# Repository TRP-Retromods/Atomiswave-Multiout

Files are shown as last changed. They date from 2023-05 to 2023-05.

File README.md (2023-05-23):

# Atomiswave Multiout
---
Get Composite, RGB or S-Video output from your Atomiswave, using the VGA output

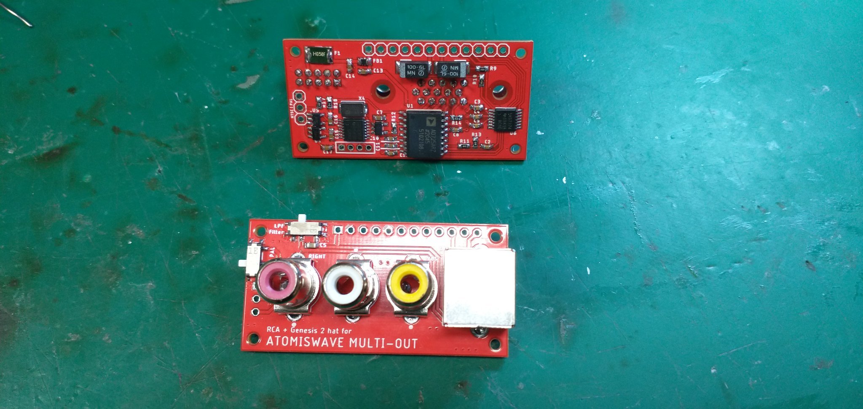
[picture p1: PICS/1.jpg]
PCB xemple

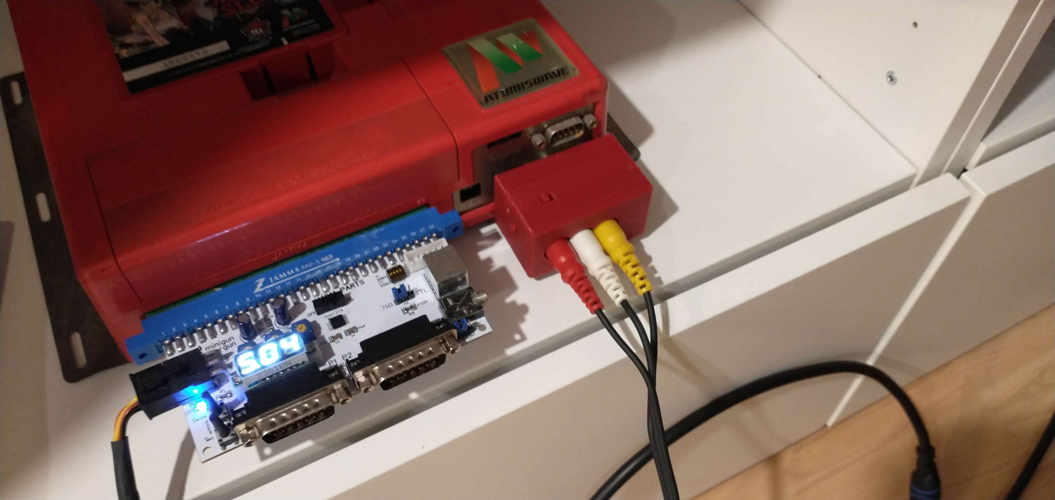
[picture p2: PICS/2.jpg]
workinunit exemple


(c) 2023 by The Real Phoenix
Design from Mike Chi's VGA2SCART

---

## Features:
- The motherboard is doing all the job, the "hat" or daughterboard is the one with the output connectors, so you can make one for your needs
- PAL/NTSC selection
- LP Filter
- Audio Line-in level is driven from the daughterboard, leaving the ability to keep pass-trought audio for amp already present inside a cabinet

## Notes:
- You'll need to program the CDCE either with using a DFO programmer or ask your ICs provider to do it for you.
- The connector to audio/power is tricky to find, I found some on eBay: https://www.ebay.ca/itm/184681041924

---
### Links for the Programmer and classic DFO:
https://nfggames.com/forum2/index.php?topic=5744.0
https://oshpark.com/profiles/micro

https://circuit-board.de/forum/index.php/Thread/7810-Sega-32X-Switchless-Mod-f%C3%BCr-Mega-Drive-1-und-auch-2/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

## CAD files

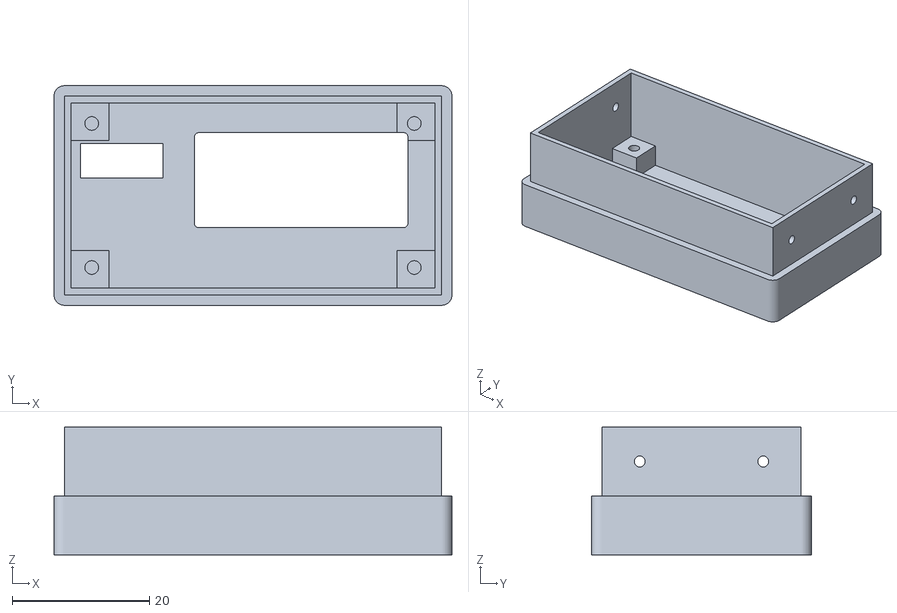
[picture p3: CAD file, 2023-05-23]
STL/Atomiswave_BOT.stl
58.0 x 32.0 x 18.6

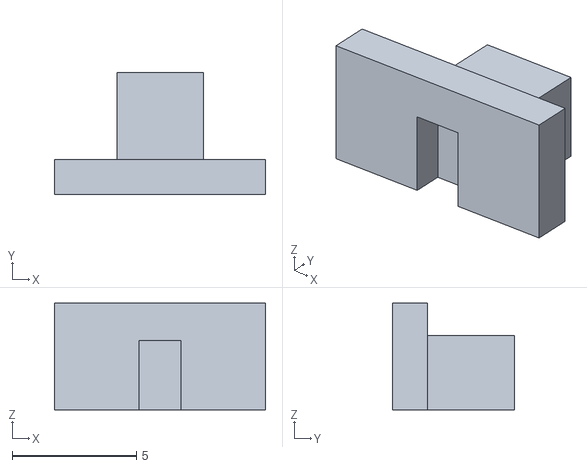
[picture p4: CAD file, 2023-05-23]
STL/Atomiswave_Buttn.stl
8.50 x 4.90 x 4.30

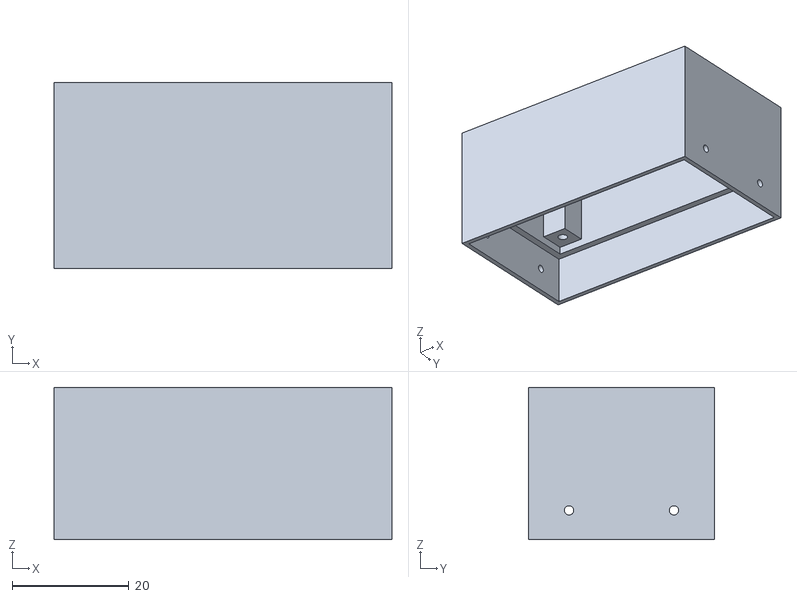
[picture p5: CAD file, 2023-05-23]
STL/Atomiswave_TOP_Empty.stl
58.0 x 32.0 x 26.1

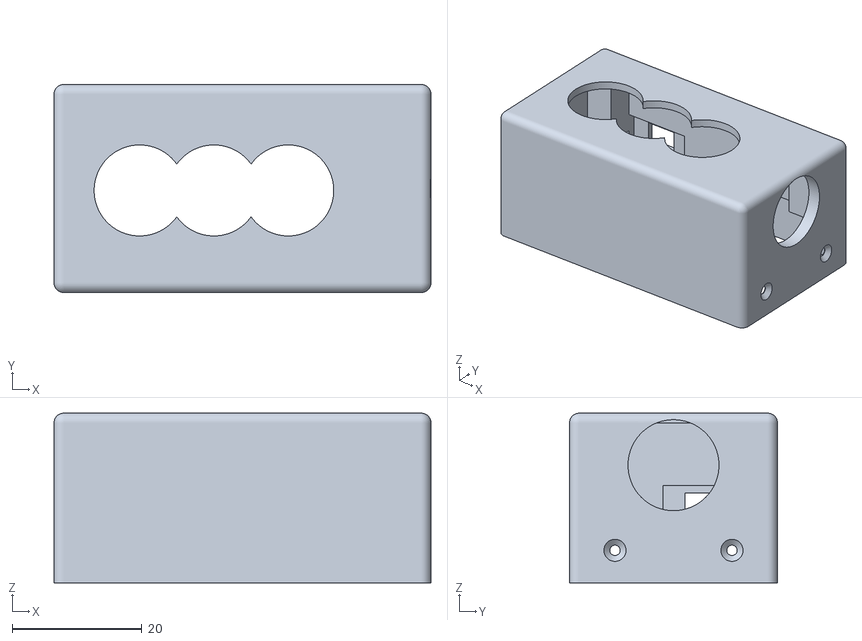
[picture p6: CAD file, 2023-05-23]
STL/Atomiswave_TOP.stl
58.0 x 32.0 x 26.1

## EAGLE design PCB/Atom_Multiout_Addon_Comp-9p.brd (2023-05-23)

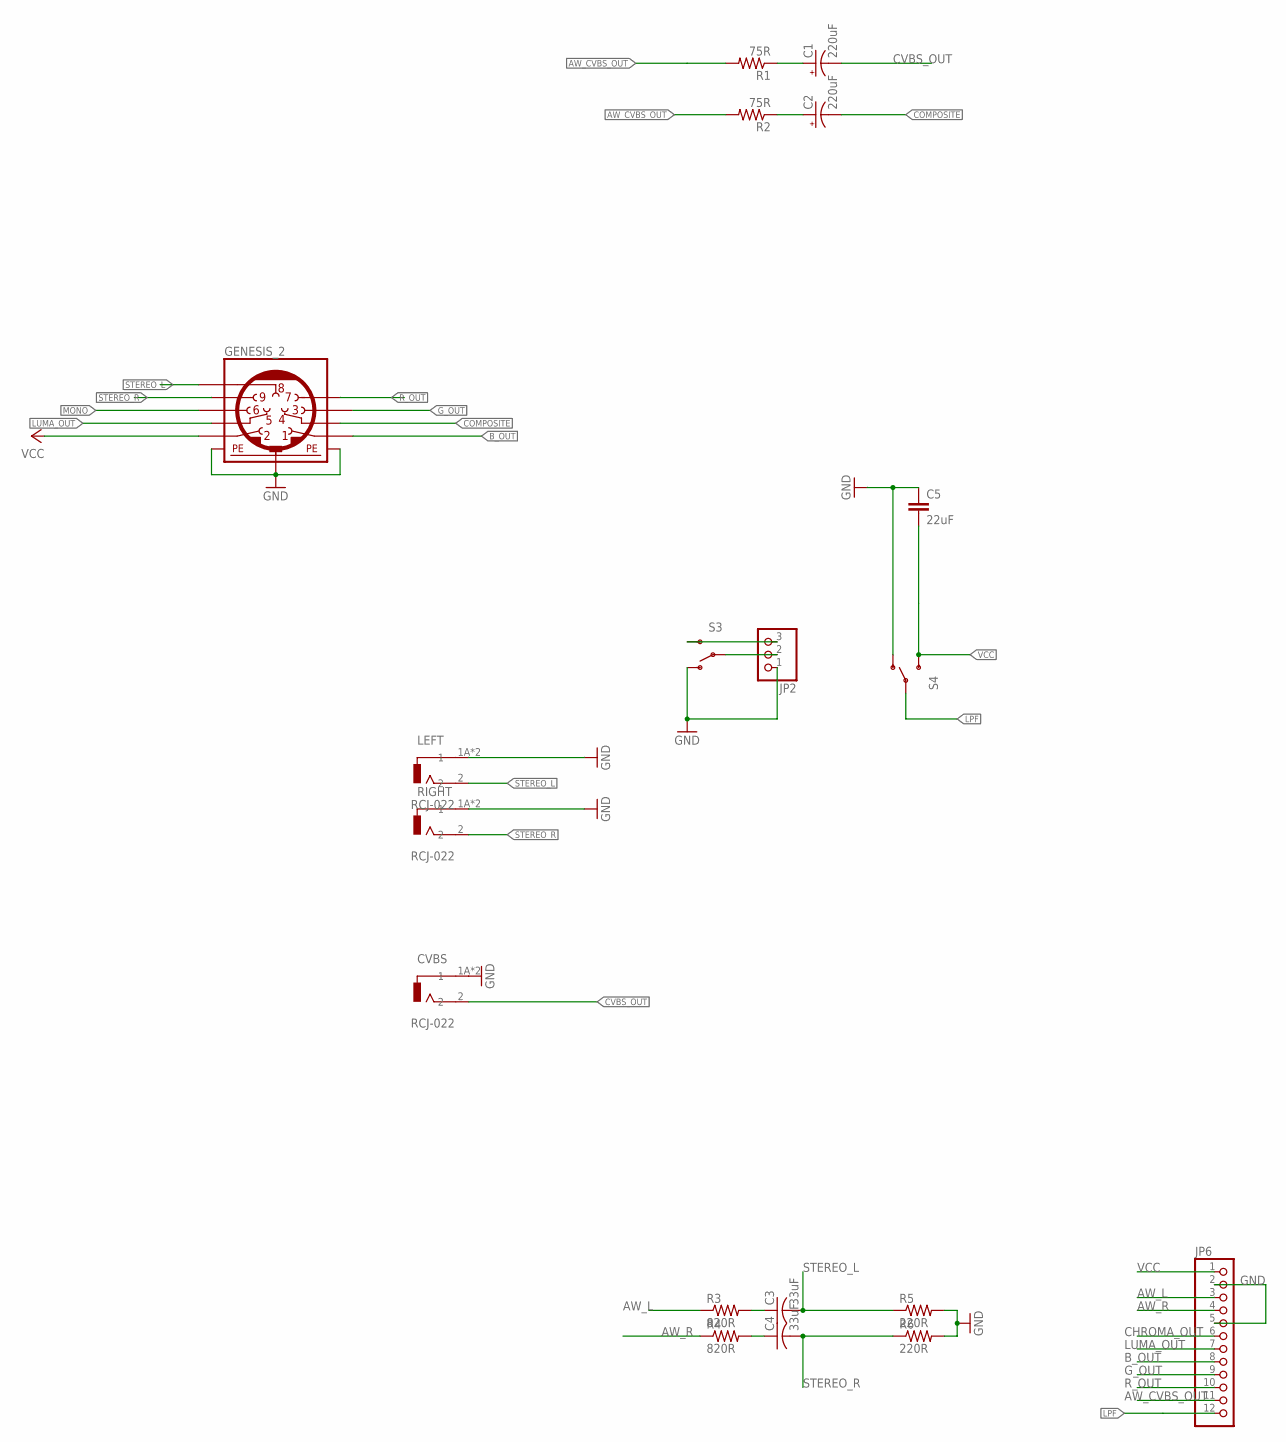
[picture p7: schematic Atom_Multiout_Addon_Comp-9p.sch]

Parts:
C1, C2: 220uF; D/7343-31W
C3, C4: 33uF; C1206K
C5: 22uF; C0603
CVBS: RCJ-022; CUI_RCJ-022
GENESIS_2: MINI_DIN_9; M_DIN9
JP2: PINHD-1X03_2.54-S; 1X03-S
JP6: PINHD-1X12_2.54-S; 1X12-S
LEFT: RCJ-022; CUI_RCJ-022
R1, R2: 75R; R1206
R3, R4: 820R; R1206
R5, R6: 220R; R1206
RIGHT: RCJ-022; CUI_RCJ-022
S3, S4: SWITCH-SPDT-SMD-A; SWITCH-SPST-SMD-A

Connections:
AW_CVBS_OUT: JP6.11, R1.2, R2.2
AW_L: JP6.3, R3.1
AW_R: JP6.4, R4.1
B_OUT: GENESIS_2.1, JP6.8
CHROMA_OUT: JP6.6
COMPOSITE: C2.-, GENESIS_2.4
CVBS_OUT: C1.-, CVBS.2
GND: C5.1, CVBS.1A (1), CVBS.1B (1), GENESIS_2.SH1 (PE1), GENESIS_2.SH2 (PE2), GENESIS_2.SH3 (PE3), JP2.1, JP6.2, JP6.5, LEFT.1A (1), LEFT.1B (1), R5.2, R6.2, RIGHT.1A (1), RIGHT.1B (1), S3.1 (O), S4.1 (O)
G_OUT: GENESIS_2.3, JP6.9
LPF: JP6.12, S4.2
LUMA_OUT: GENESIS_2.5, JP6.7
MONO: GENESIS_2.6
unnamed: C2.+, R2.1
unnamed: JP2.3, S3.3 (S)
unnamed: C1.+, R1.1
unnamed: C4.1, R4.2
unnamed: C3.1, R3.2
unnamed: JP2.2, S3.2
R_OUT: GENESIS_2.7, JP6.10
STEREO_L: C3.2, GENESIS_2.8, LEFT.2, R5.1
STEREO_R: C4.2, GENESIS_2.9, R6.1, RIGHT.2
VCC: C5.2, GENESIS_2.2, JP6.1, S4.3 (S)

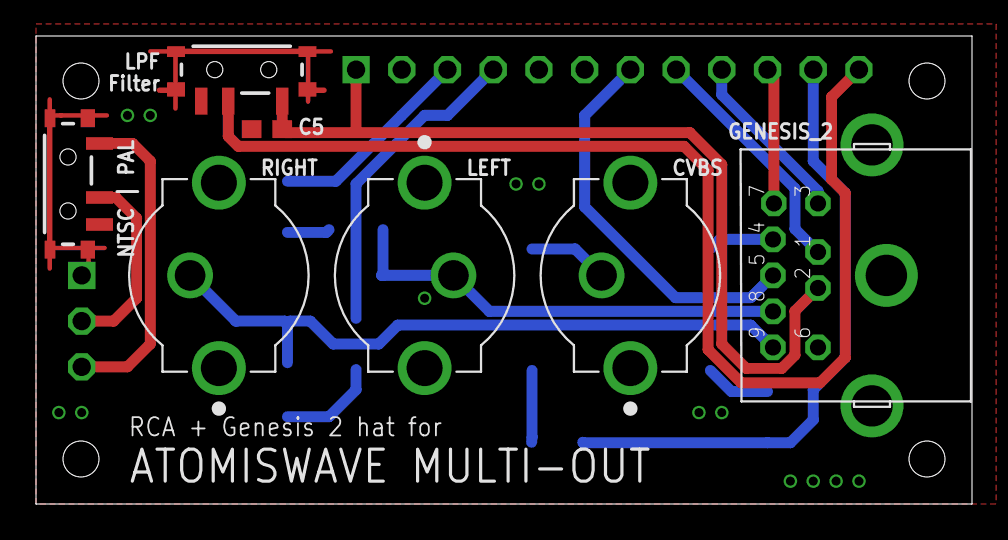
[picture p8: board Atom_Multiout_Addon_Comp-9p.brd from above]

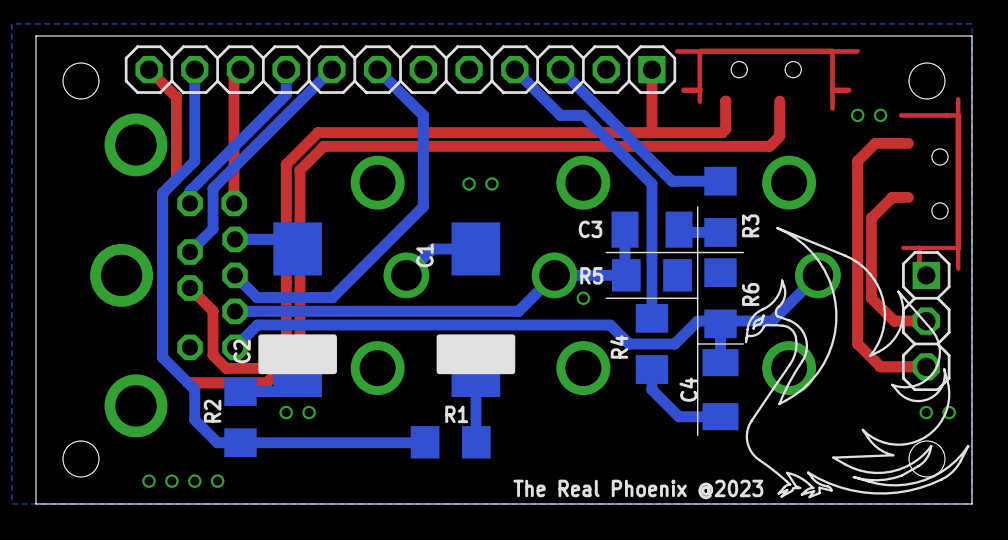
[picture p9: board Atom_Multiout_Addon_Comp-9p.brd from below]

Board: 2 copper layers, 52.0 x 26.0 mm, 20 parts (13 on the bottom side), 20 nets.

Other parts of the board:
U$1: LOGO

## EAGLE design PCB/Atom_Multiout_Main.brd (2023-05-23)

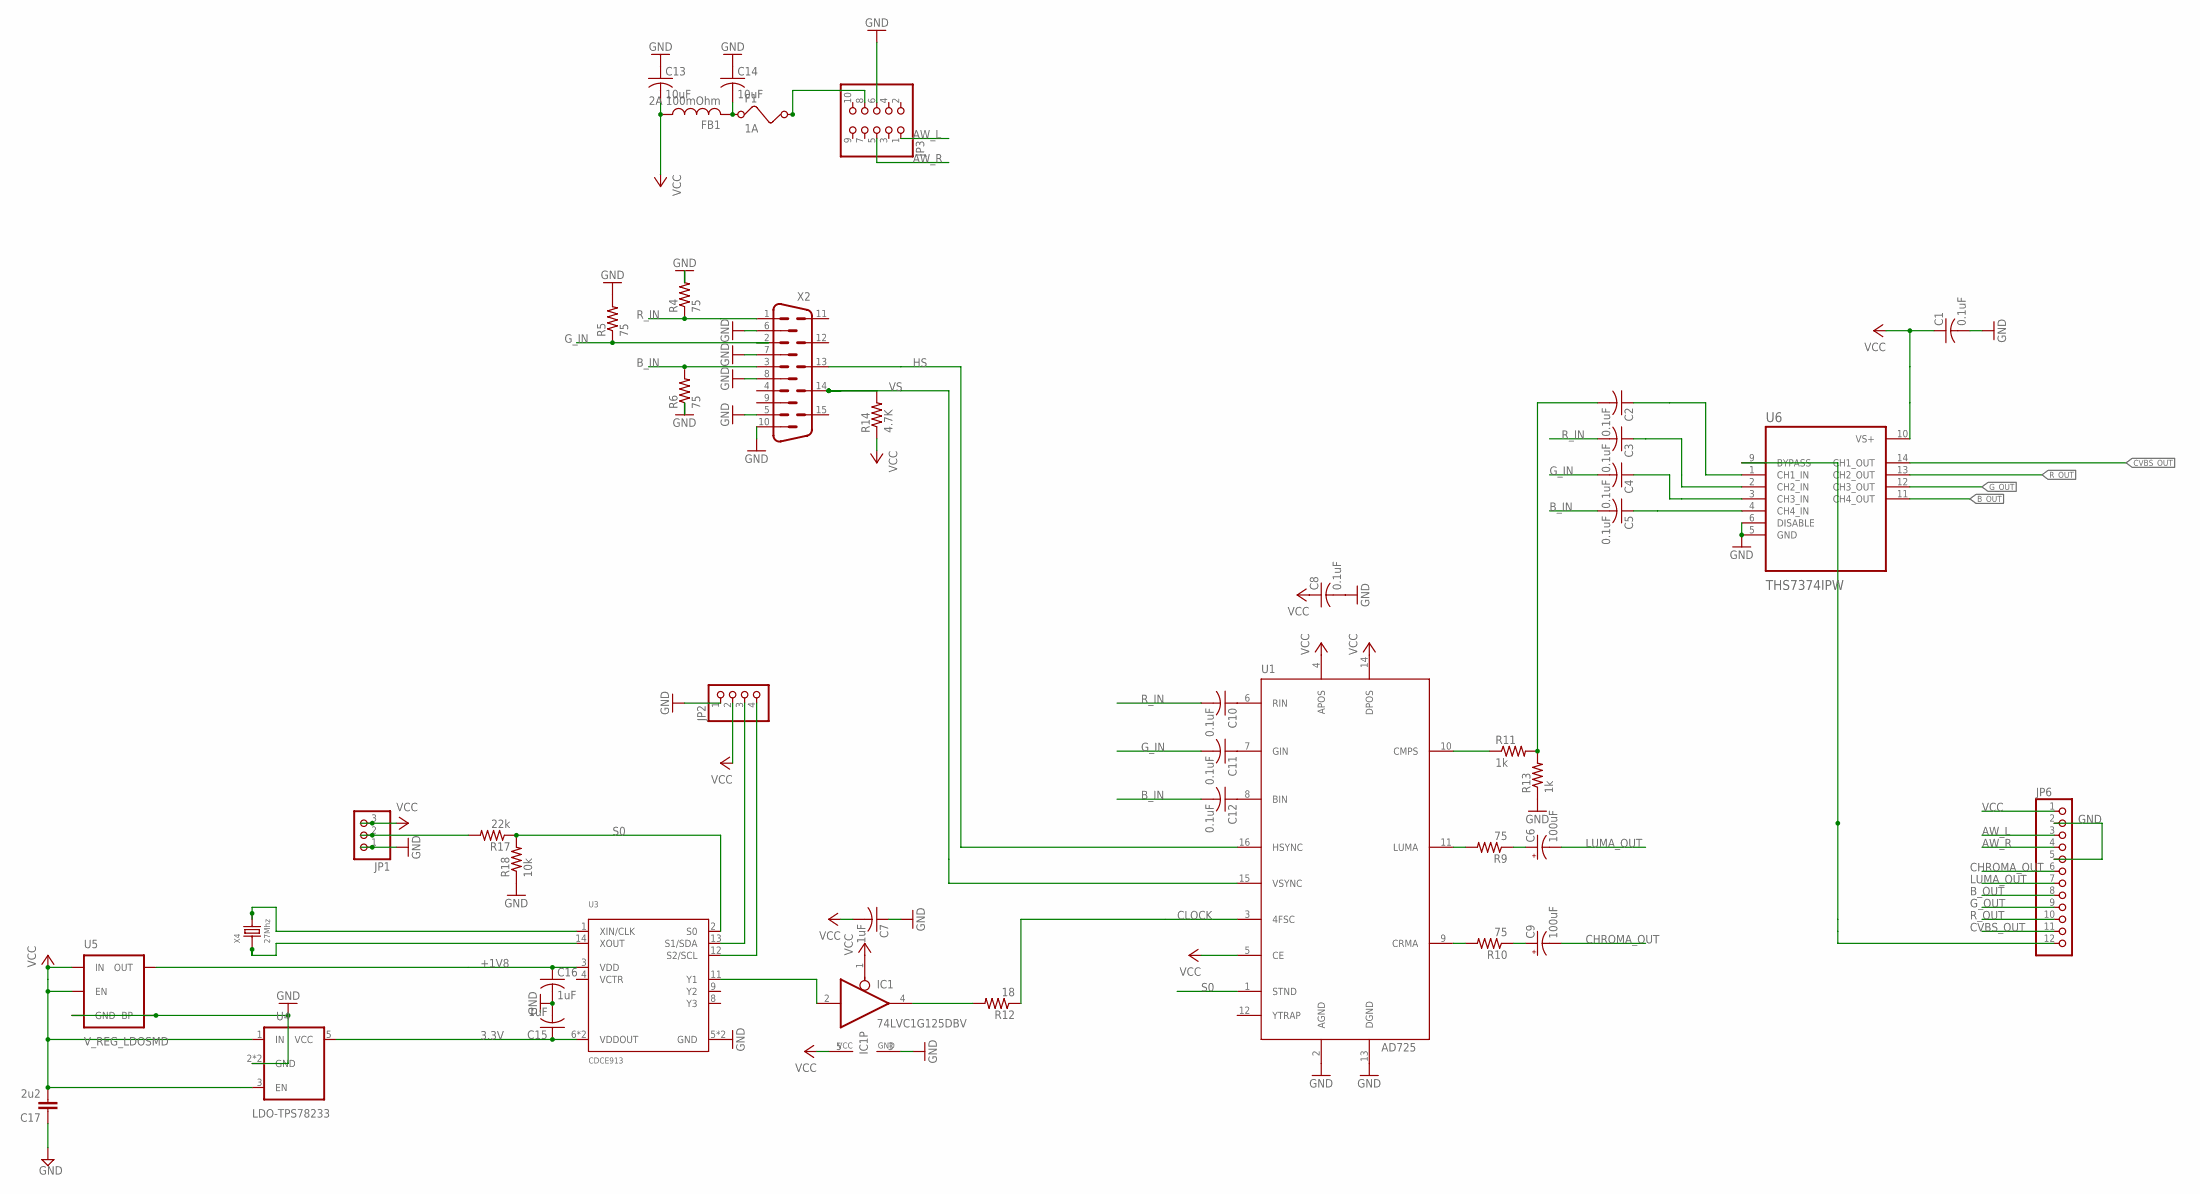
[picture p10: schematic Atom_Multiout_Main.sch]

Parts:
C1, C2, C3, C4, C5, C8, C10, C11, C12: 0.1uF; C0603@1
C6, C9: 100uF; C/6032-28R
C7, C15, C16: 1uF; C0603@1
C13, C14: 10uF; C0603@1
C17: 2u2; C0603
F1: 1A; 1812
FB1: 2A 100mOhm; 0805
IC1: 74LVC1G125DBV; SOT23-5
JP1: PINHD-1X03_2.54-S; 1X03-S
JP2: PINHD-1X04_2.00; 1X04M
JP3: PINHD-2X05_2.00; 2X05M
JP6: PINHD-1X12_2.54-S; 1X12-S
R4, R5, R6, R9, R10: 75; R0603
R11, R13: 1k; R0603
R12: 18; R0603
R14: 4.7K; R0603
R17: 22k; R0603
R18: 10k; R0603
U1: AD725; SOIC16W
U3: CDCE913; TSSOP14
U4: LDO-TPS78233; SOT23-5
U5: V_REG_LDOSMD; SOT23-5
U6: THS7374IPW; SOP65P640X120-14N
X2: HM15V; HDM15V
X4: 27Mhz; X2-SMD-5.0X3.2X1.3MM

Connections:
3.3V: C15.1, U3.6 (VDDOUT), U3.7 (VDDOUT), U4.5 (VCC)
+1V8: C16.1, U3.3 (VDD), U5.5 (OUT)
AW_L: JP3.1, JP6.3
AW_R: JP3.5, JP6.4
B_IN: C5.2, C12.2, R6.2, X2.3
B_OUT: JP6.8, U6.11 (CH4_OUT)
CHROMA_OUT: C9.-, JP6.6
CLOCK: R12.1, U1.3 (4FSC)
CVBS_OUT: JP6.11, U6.14 (CH1_OUT)
GND: C1.2, C7.1, C8.2, C13.1, C14.1, C15.2, C16.2, C17.1, IC1.3 (GND), JP1.1, JP2.1, JP3.6, JP6.2, JP6.5, R4.2, R5.2, R6.1, R13.1, R18.1, U1.2 (AGND), U1.13 (DGND), U3.5 (GND), U3.10 (GND), U4.2 (GND), U4.4 (GND), U5.2 (GND), U5.4 (BP), U6.5 (GND), U6.6 (DISABLE), X2.5, X2.6, X2.7, X2.8, X2.10
G_IN: C4.2, C11.2, R5.1, X2.2
G_OUT: JP6.9, U6.12 (CH3_OUT)
HS: U1.16 (HSYNC), X2.13
LPF: JP6.12, U6.9 (BYPASS)
LUMA_OUT: C6.-, JP6.7
unnamed: C2.1, U6.1 (CH1_IN)
unnamed: IC1.4 (O), R12.2
unnamed: C4.1, U6.3 (CH3_IN)
unnamed: C3.1, U6.2 (CH2_IN)
unnamed: C5.1, U6.4 (CH4_IN)
unnamed: C2.2, R11.2, R13.2
unnamed: R11.1, U1.10 (CMPS)
unnamed: C10.1, U1.6 (RIN)
unnamed: C11.1, U1.7 (GIN)
unnamed: C12.1, U1.8 (BIN)
unnamed: R9.2, U1.11 (LUMA)
unnamed: R10.2, U1.9 (CRMA)
unnamed: C6.+, R9.1
unnamed: C9.+, R10.1
unnamed: F1.2, JP3.8
unnamed: C14.2, F1.1, FB1.2
unnamed: IC1.2 (I), U3.11 (Y1)
unnamed: JP1.2, R17.2
unnamed: U3.1 (XIN/CLK), X4.2
unnamed: U3.14 (XOUT), X4.1
unnamed: JP2.3, U3.13 (S1/SDA)
unnamed: JP2.4, U3.12 (S2/SCL)
R_IN: C3.2, C10.2, R4.1, X2.1
R_OUT: JP6.10, U6.13 (CH2_OUT)
S0: R17.1, R18.2, U1.1 (STND), U3.2 (S0)
VCC: C1.1, C7.2, C8.1, C13.2, C17.2, FB1.1, IC1.1 (OE), IC1.5 (VCC), JP1.3, JP2.2, JP6.1, R14.1, U1.4 (APOS), U1.5 (CE), U1.14 (DPOS), U4.1 (IN), U4.3 (EN), U5.1 (IN), U5.3 (EN), U6.10 (VS+)
VS: R14.2, U1.15 (VSYNC), X2.14

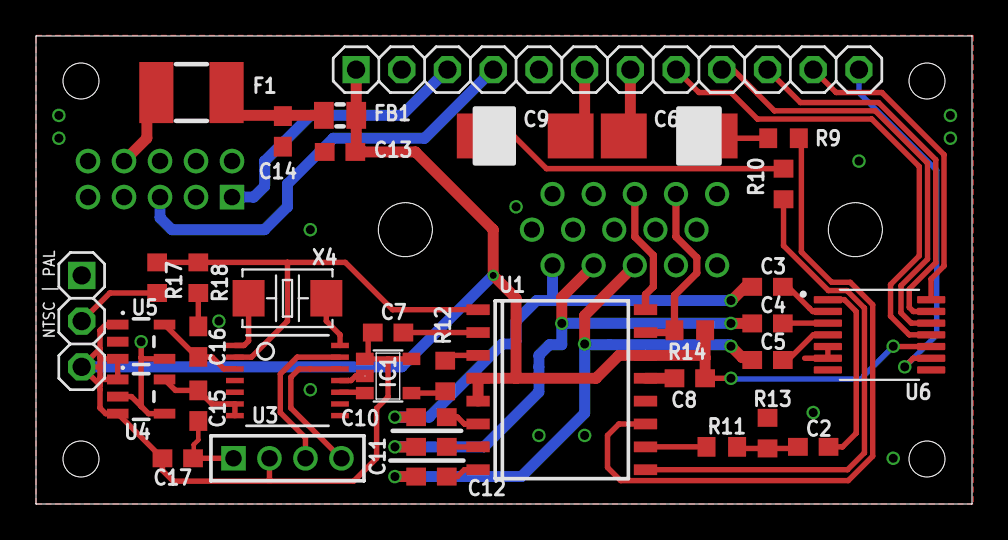
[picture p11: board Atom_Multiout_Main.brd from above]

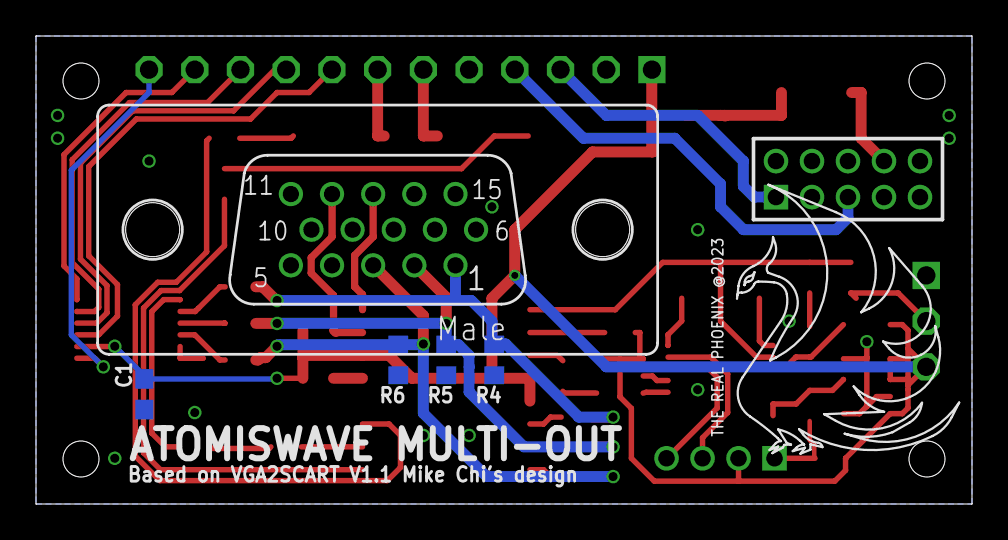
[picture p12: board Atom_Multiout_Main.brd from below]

Board: 2 copper layers, 52.0 x 26.0 mm, 43 parts (7 on the bottom side), 42 nets.

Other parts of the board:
U$1: LOGO

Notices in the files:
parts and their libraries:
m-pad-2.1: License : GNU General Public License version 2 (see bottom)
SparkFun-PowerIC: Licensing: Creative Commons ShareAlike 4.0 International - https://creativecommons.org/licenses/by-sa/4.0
